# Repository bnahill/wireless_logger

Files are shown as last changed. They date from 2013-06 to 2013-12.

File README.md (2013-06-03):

Wireless Logger
===============

A compact wireless inertial logging and processing hardware platform. This may include multiple designs of different names. Software may also be included soon.

Licensing
=========

Hardware designs in this package are licensed under the TAPR Open Hardware License v1.0.

Software presented here is licensed under the GNU General Public License version 3 (GPLv3).

The terms of both licenses are included in this repository. If you would like to use these works in another projects which would otherwise violate the terms of their respective licenses, please contact me and perhaps we can work something out. While I support both the free hardware/software movements, I understand that such licenses may excessively constrain groups with otherwise noble causes.

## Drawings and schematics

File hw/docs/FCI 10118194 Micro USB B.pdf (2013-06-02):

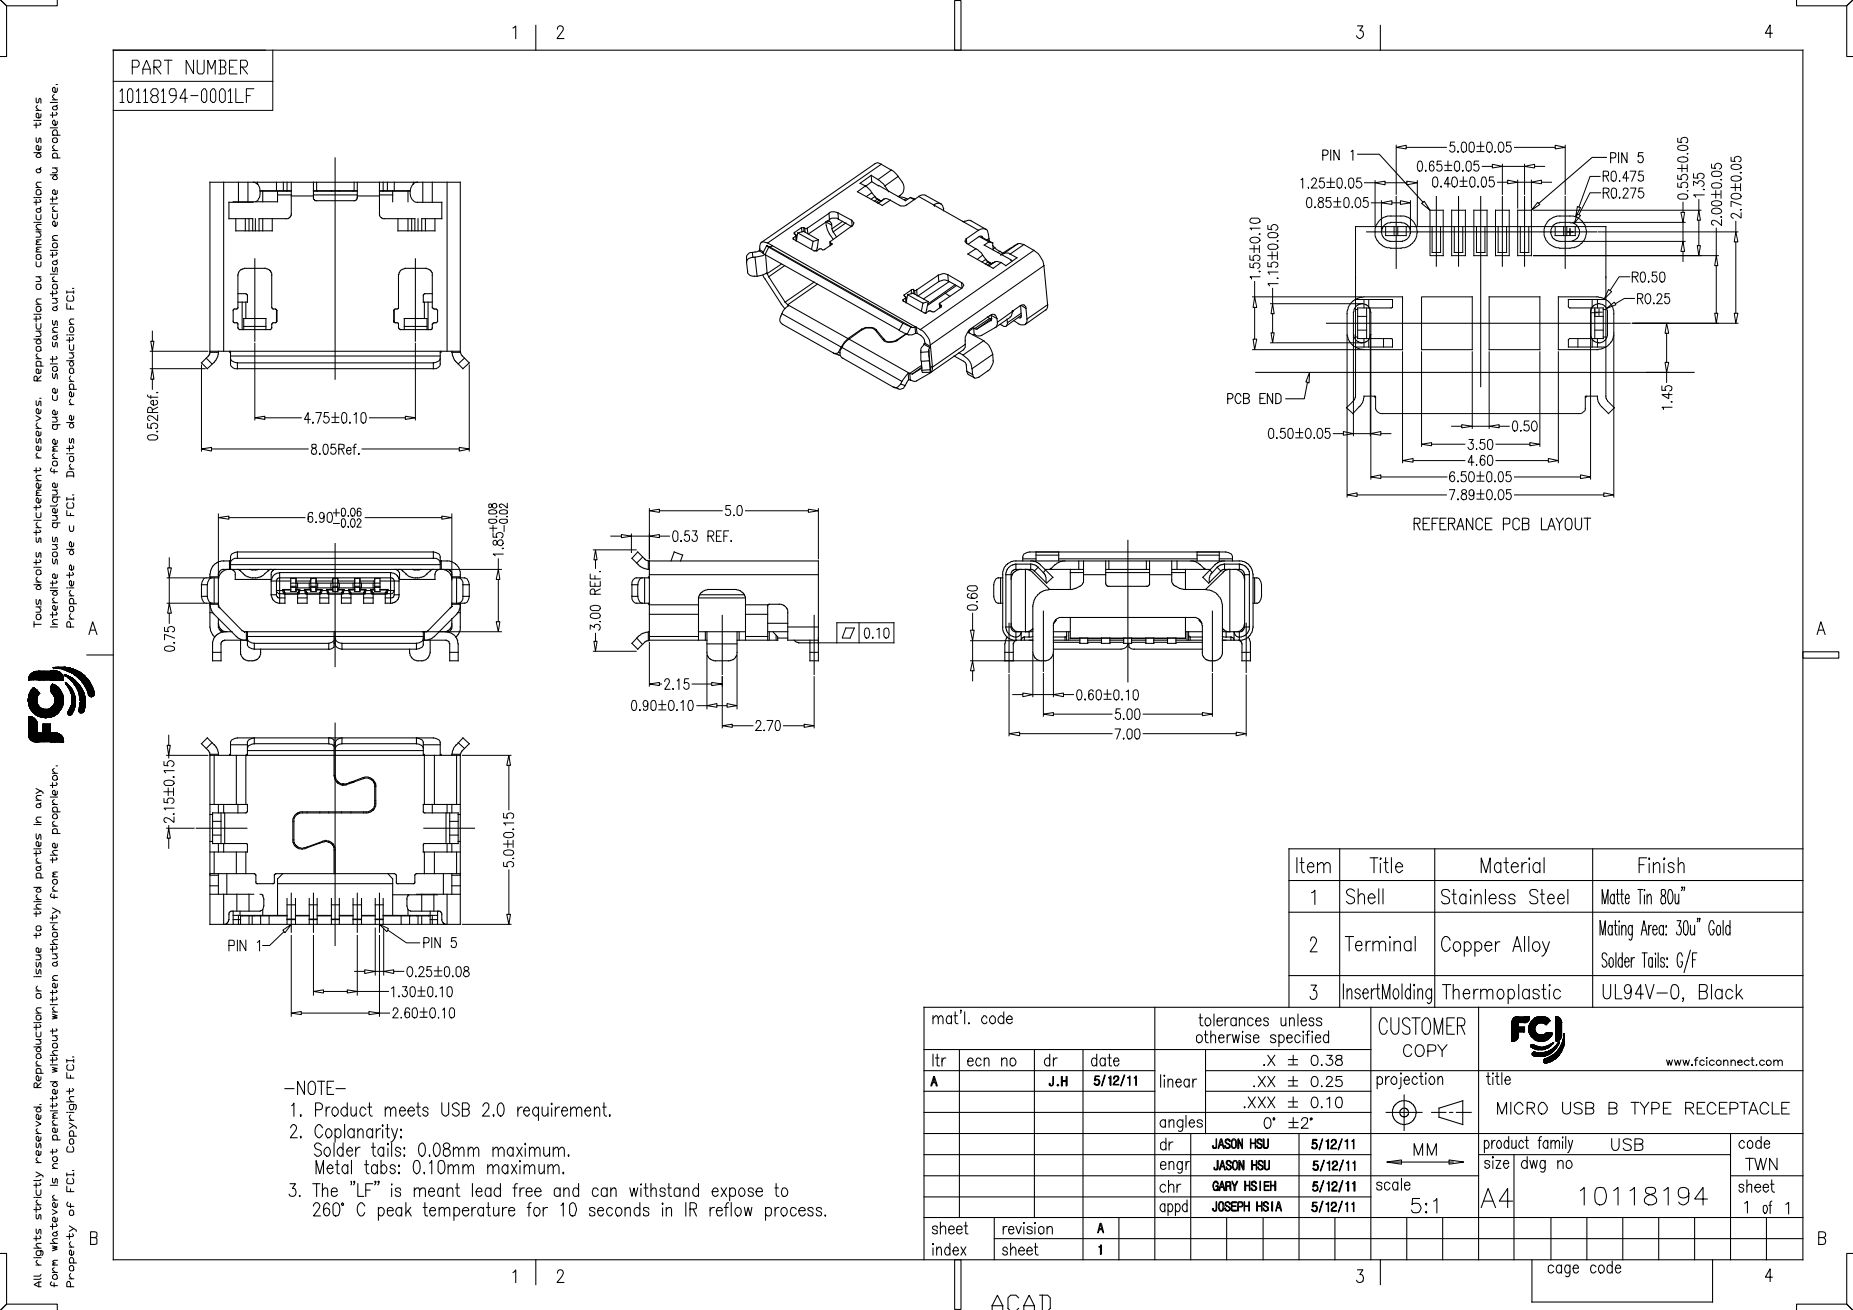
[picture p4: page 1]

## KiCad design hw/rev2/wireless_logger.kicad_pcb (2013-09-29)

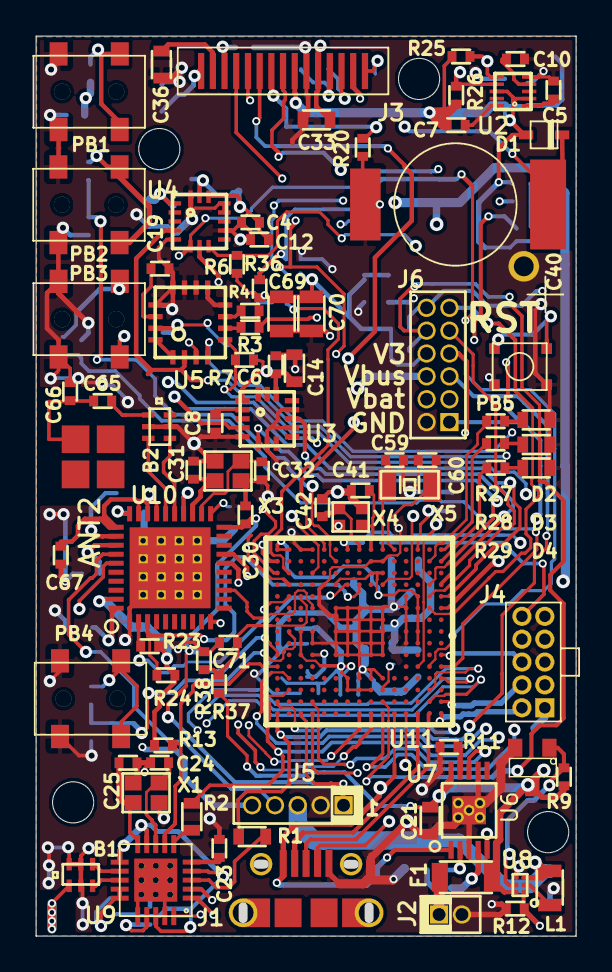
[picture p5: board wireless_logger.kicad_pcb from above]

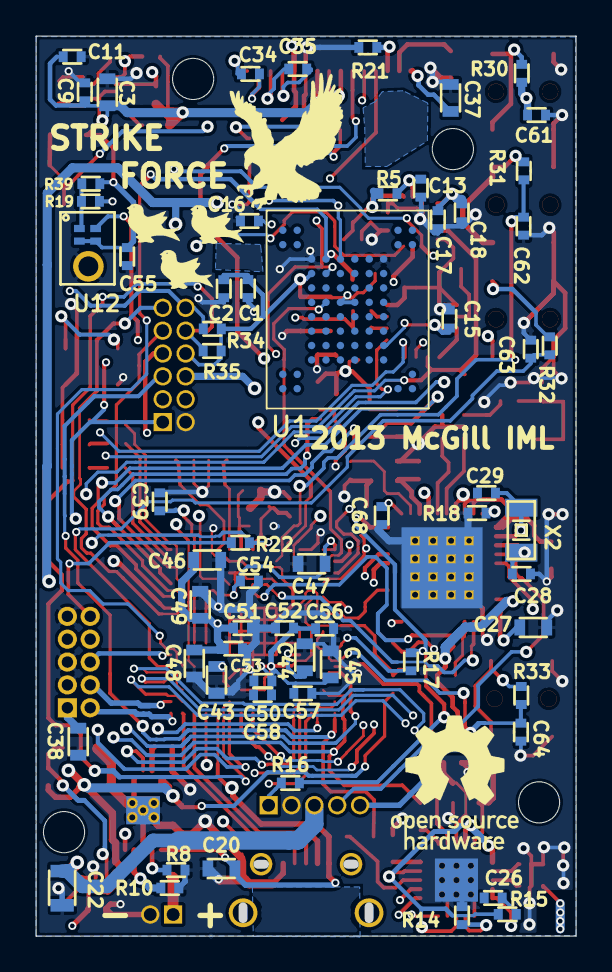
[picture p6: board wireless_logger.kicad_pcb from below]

Board: 4 copper layers, 30.0 x 50.0 mm, 155 parts (66 on the bottom side), 112 nets.

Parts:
ANT2: Molex 47948; MOLEX_47948
B1: 0915BM15A0001; JOHAN_BALUN_FILT
B2: 2450BM15A0002; JOHAN_BALUN_FILT
C1, C55: 0.1u; SMD0402
C2, C7, C18, C34, C35, C67, C68, C71: 1u; SMD0402
C3, C14, C20, C21, C33, C36, C37, C38, C43, C44, C45, C46, C47, C48, C49: 2.2u; SMD0603
C4, C5, C8, C9, C10, C11, C12, C15, C17, C23, C50, C51, C52, C53, C61, C62, C63, C64: 100n; SMD0402
C6, C16: 100p; SMD0402
C13, C19, C26, C39, C54, C56, C57, C58: 10n; SMD0402
C22, C69, C70: 10u; SMD0805
C24, C25, C41, C42: 5p; SMD0402
C27: 1u; SMD0603
C28, C29: 15p; SMD0402
C30: 1n; SMD0402
C31, C32: 12p; SMD0402
C40: DSK-3R3H224U-HL; DSK-XXXXXX-HL
C59, C60: 9p; SMD0402
C65, C66: CAP; SMD0402
D1: BAT43XV2; SOD-523F
D2: LS Q976-NR-1; SMD0603
D3: LW Q38G-Q1S1-3K6L-1; SMD0603
D4: LB Q39E-N1P1-35-1; SMD0603
F1: PTS120616V025; SMD1206
J1: FCI 10118194; FCI_10118194
J2: CONN_2; HDR_2X1_50MIL
J3: SSD1306_SER; LY091WG15
J4: SWD_10PIN; SULLINS_5X2_050_THRU
J5: CONN_5; HDR_5X1_50MIL
J6: CONN_6X2; HDR_6X2_50MIL
L1: MLP2016S1R0M; SMD0805
PAD_0_5x1_5: VAL**; PAD_0_5x1_5
PB1, PB2, PB3, PB4: EVQPSD
PB5: KMT0
R1, R2: 100k; SMD0603
R3, R4: 4.7k; SMD0402
R5: 4.7R; SMD0402
R6, R7, R13: 220k; SMD0402
R8: 1k; SMD0402
R9: 680k; SMD0402
R10: 2k; SMD0402
R11, R12: 470k; SMD0402
R14, R18: 56k (1%); SMD0402
R15: 4R7; SMD0402
R16: 2.7k; SMD0402
R17: 22k; SMD0402
R19: 0R; SMD0402
R20, R36: 100k; SMD0402
R21: 390k; SMD0402
R22, R23, R24, R25, R26, R34, R35: 10k; SMD0402
R27, R28, R29: RES; SMD0402
R30, R31, R32, R33: 3.3k; SMD0402
R37, R38, R39: 1M; SMD0402
SCREW_HOLE_2-56, SCREW_HOLE_2-56#2, SCREW_HOLE_2-56#3, SCREW_HOLE_2-56#4: VAL**; SCREW_HOLE_2-56
U1: MT29FXX01A; MICRON_VFBGA63
U2: MAG3110
U3: MMA8452Q; MMA8451Q
U4: LPS331AP
U5: L3GD20
U6: MCP111T-315; SOT23
U7: BQ24095; BQ24095_MSOP
U8: TPS62698
U9: CC1101
U10: CC2541
U11: STM32F40X_BGA176; STM32F4_BGA176
U12: MEMS_DGTL_MIC; ADMP521
VAL: MCGILL
VAL#2: EAGLE
VAL#3: OSHW
X1: FA-128 26.0000MF10Z-W3; FA-128
X2, X5: 9HT10-32.768KBZF-T; TXC_9HT10
X3: FA-128 32.0000MF20X-K3; FA-128
X4: XRCGB25M000F0L00R0; XRCGB_F_N

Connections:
/Bluetooth/BT_ANT_DN: B2.3, U10.26
/Bluetooth/BT_ANT_DP: B2.4, U10.25
/Bluetooth/BT_ANT_SE: ANT2.1, C65.2, C66.1
/Bluetooth/RF_DC: J5.4, U10.34
/Bluetooth/RF_DD: J5.5, U10.35
/Bluetooth/RF_RESET_N_LOCAL: C30.2, R16.1, R17.1, U10.20
/Bluetooth/RX_MISO: U10.17, U11.H15
/Bluetooth/TX_MOSI: U10.16, U11.G15
/Guardian Interface/GDO0: R2.1, U9.6
/Guardian Interface/GDO2: R1.1, U9.3
/OLED/SCLK: J3.11, U1.K6, U11.P4
/OLED/SDIN: J3.12, U1.J7, U11.R3
/Power/MODE: R12.2, U8.A1, U11.N15
/STM32F4/BT_NRESET: R17.2, U11.R10
/STM32F4/CC1101_nCS: R13.2, U9.7, U11.R11
/STM32F4/EXTI1: R3.1, R4.1, U11.M3
/STM32F4/EXTI2: U10.13, U11.M6
/STM32F4/EXTI5: C61.2, R30.2, U11.P5
/STM32F4/EXTI6: C62.2, R31.2, U11.K2
/STM32F4/EXTI7: C63.2, R32.2, U11.A11
/STM32F4/EXTI8: C64.2, R33.2, U11.P8
/STM32F4/FLASH_nCS: R36.1, U1.K7, U11.B11
/STM32F4/GYRO_nCS: R7.1, U5.5, U11.A6
/STM32F4/I2C2_SCL: R24.2, U10.3, U11.H4
/STM32F4/I2C2_SDA: R23.2, U10.2, U11.J4
/STM32F4/I2C3_SCL: J6.12, R34.2, U11.F15
/STM32F4/I2C3_SDA: J6.10, R35.2, U11.F14
/STM32F4/LED1: R27.2, U11.B2
/STM32F4/LED2: R28.2, U11.A1
/STM32F4/LED3: R29.2, U11.A2
/STM32F4/OLED_nCS: J3.8, U11.L1
/STM32F4/OLED_nD/C: J3.10, U11.R2
/STM32F4/OLED_nRES: J3.9, R20.2, U11.F4
/STM32F4/REG_nCHG: U7.8, U11.M14
/STM32F4/REG_nUSB_CONN: U7.5, U11.M15
/STM32F4/SPI1_MISO: U1.G7, U11.P3
/STM32F4/SPI2_CLK: J6.1, R2.2, R19.1, U11.P13
/STM32F4/SPI2_MISO: J6.3, U11.R14, U12.DAT
/STM32F4/SPI2_MOSI: J6.5, R1.2, U11.R15
/STM32F4/SPI2_NSS: J6.7, U11.P12
/STM32F4/SWCLK: J4.4, U11.A14
/STM32F4/SWDIO: J4.2, U11.A15
/STM32F4/SWO: J4.6, U11.A10
/STM32F4/USART1_RX: J6.9, U11.B5
/STM32F4/USART1_TX: J6.11, U11.B6
/STM32F4/USB_D+: J1.3, U11.B15
/STM32F4/USB_D-: J1.2, U11.C15
/STM32F4/USB_ID: J1.4, U11.D15
/Sensors/ACC_I2C_SCL: R26.2, U2.7, U3.4, U11.A5
/Sensors/ACC_I2C_SDA: R25.2, U2.6, U3.6, U11.B4
/Sensors/ACC_INT1: U3.11, U11.A4
/Sensors/GYR_DRDY_INT2: R3.2, U5.6
/Sensors/GYR_INT1: R4.2, U5.7
/Sensors/GYR_SPI_CLK: U4.4, U5.2, U9.1, U11.B14
/Sensors/GYR_SPI_MISO: U4.7, U5.4, U9.2, U11.B13
/Sensors/GYR_SPI_MOSI: U4.6, U5.3, U9.20, U11.A12
/Sensors/PRS_SPI_nCS: R6.1, U4.8, U11.C11
GND: B1.2, B1.5, B1.6, B2.2, B2.5, B2.6, C1.1, C2.1, C3.1, C4.1, C5.1, C6.1, C7.1, C8.1, C9.1, C10.1, C11.1, C12.1, C13.1, C14.1, C15.1, C16.1, C17.1, C18.1, C19.2, C20.1, C21.1, C22.1, C23.1, C24.1, C25.1, C26.1, C27.1, C28.2, C29.2, C30.1, C31.2, C32.2, C33.1, C36.1, C37.1, C38.1, C39.1, C40.2, C41.2, C42.2, C43.1, C44.1, C45.1, C46.1, C47.1, C48.1, C49.1, C50.1, C51.1, C52.1, C53.1, C54.1, C55.1, C56.1, C57.1, C58.1, C59.2, C60.2, C61.1, C62.1, C63.1, C64.1, C66.2, C67.1, C68.1, C69.1, C70.1, C71.1, D2.2, D3.2, D4.2, J1.5, J2.2, J3.6, J4.3, J4.5, J4.9, J5.2, J6.2, PB1.2, PB2.2, PB3.2, PB4.2, PB5.2, R8.1, R10.1, R11.1, R12.1, R14.1, R18.2, R20.1, R21.1, R38.1, U1.K3, U1.K8, U2.5, U2.10, U3.5, U3.7, U3.10, U3.12, U4.5, U4.10, U4.12, U4.13, U4.16, U5.8, U5.9, U5.10, U5.11, U5.12, U5.13, U6.2, U7.3, U7.7, U7.GND, U8.C2, U9.16, U9.19, U9.GND, U10.1, U10.GND, U11.D5, U11.D6, U11.D7, U11.D8, U11.D9, U11.F2, U11.F6, U11.F7, U11.F8, U11.F9, U11.F10, U11.F12, U11.G2, U11.G6, U11.G7, U11.G8, U11.G9, U11.G10, U11.G12, U11.H6, U11.H7, U11.H8, U11.H9, U11.H10, U11.H12, U11.J6, U11.J7, U11.J8, U11.J9, U11.J10, U11.K6, U11.K7, U11.K8, U11.K9, U11.K10, U11.L4, U11.M1, U11.M8, U11.M9, U11.N1, U12.GND, X1.GND, X3.GND, X4.GND
unnamed: PB2.1, R31.1
unnamed: PB4.1, R33.1
unnamed: PB3.1, R32.1
unnamed: PB1.1, R30.1
unnamed: R19.2, R39.2, U12.CLK
unnamed: C60.1, U11.E1, X5.1
unnamed: C39.2, C40.1, D1.2, U11.C1
unnamed: C43.2, U11.F13
unnamed: C44.2, U11.M10
unnamed: J4.10, R22.2
unnamed: C42.1, U11.H1, X4.2
unnamed: C41.1, U11.G1, X4.1
unnamed: C71.2, R37.1, R38.2, U11.N5
unnamed: C59.1, U11.F1, X5.2
unnamed: D2.1, R27.1
unnamed: D4.1, R29.1
unnamed: D3.1, R28.1
unnamed: PB5.1, R22.1, U11.J1
unnamed: C13.2, R5.2, U4.15
unnamed: C5.2, U2.1
unnamed: C10.2, U2.4
unnamed: C8.2, U3.2
unnamed: C19.1, U5.14
unnamed: R8.2, U7.2
unnamed: R11.2, U7.9
unnamed: R10.2, U7.4
unnamed: L1.1, U8.B1
unnamed: F1.1, J2.1
unnamed: R9.1, U6.1, U8.B2
unnamed: R14.2, U9.17
unnamed: C24.2, U9.8, X1.1
unnamed: C25.2, U9.10, X1.2
unnamed: C26.2, R15.1, U9.14, U9.15
unnamed: B1.3, U9.13
unnamed: B1.4, U9.12
unnamed: C23.2, U9.5
unnamed: R18.1, U10.30
unnamed: C27.2, U10.40
unnamed: C29.1, U10.32, X2.2
unnamed: B2.1, C65.1
unnamed: C28.1, U10.33, X2.1
unnamed: J5.1, R16.2
unnamed: C32.1, U10.22, X3.1
unnamed: C31.1, U10.23, X3.2
unnamed: C37.2, J3.15
unnamed: C36.2, J3.14
unnamed: J3.13, R21.2
unnamed: C34.2, J3.2
unnamed: C34.1, J3.1
unnamed: C35.1, J3.3
unnamed: C35.2, J3.4
V3: C1.2, C2.2, C3.2, C4.2, C6.2, C7.2, C9.2, C11.2, C12.2, C14.2, C15.2, C16.2, C17.2, C18.2, C22.2, C38.2, C45.2, C46.2, C47.2, C48.2, C49.2, C50.2, C51.2, C52.2, C53.2, C54.2, C55.2, C56.2, C57.2, C58.2, C67.2, C68.2, C69.2, C70.2, D1.1, J3.7, J4.1, J5.3, J6.8, L1.2, R5.1, R6.2, R7.2, R13.1, R15.2, R23.1, R24.1, R25.1, R26.1, R34.1, R35.1, R36.2, R39.1, U1.D3, U1.G5, U1.G6, U1.J8, U2.2, U2.8, U3.1, U3.14, U4.1, U4.14, U5.1, U5.15, U5.16, U8.C1, U9.4, U9.9, U9.11, U9.18, U10.10, U10.21, U10.24, U10.27, U10.28, U10.29, U10.31, U10.39, U11.C5, U11.C6, U11.C7, U11.C8, U11.C9, U11.F3, U11.G3, U11.G13, U11.H13, U11.J12, U11.J13, U11.K4, U11.N8, U11.N9, U11.N10, U11.P1, U11.R1, U12.LR, U12.VDD
Vbat: C21.2, C33.2, F1.2, J3.5, J6.4, R9.2, R37.2, U6.3, U7.10, U8.A2
Vbus: C20.2, J1.1, J6.6, U7.1, U11.E15

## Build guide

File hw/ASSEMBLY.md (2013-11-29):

Hardware Assembly
=================
This document refers to **rev2c**. Rev2a and b are no longer supported and no hardware of those revisions should be assembled.

**Note for rev2a-c: XRCGB crystal footprints are flipped! This applies to the 25MHz, 26MHz, and 32MHz crystals in the design. It's easy enough to mount them rotated 90 degrees but also please take a moment to consider the value of design reviews. Unfortunately, they only help if the documentation is actually clear about whether a given drawing is from top or bottom...**

This document does not teach any skills involved. If you don't have experience with hot air reworking and soldering, you will have a very uncomfortable time and are extremely likely to break things. A lifted pad under any component can mean the entire board and many of the components on it are wasted, so please practice on something else first. THIS IS NOT AN EASY BOARD TO ASSEMBLE.

Assembly of the Strike Force rev2c board requires a number of tools:
* Soldering iron
* Hot-air rework station (prefered) or oven
* Vise
* Fine tweezers
* A solder paste in a syringe
* Solder wire of your choice, preferably thin (0.08cm will do, smaller preferable)
* Some flux, preferably in pen form
* Kapton (or other high-temperature) tape (maybe not required)
* Microscope (optional)

For assembly by hand, I recommend assembling the board in stages, defined by both regions and functionality, to reduce the search space if errors occur.

First, I recommend to assemble the power supply. Add all components in the region, including the USB port. This is to ensure that the rest of the components will receive a safe voltage when they are populated. Mounting the TPS62698 is not as bad as it looks as long as you get the orientation right. Pin A1 is the one with a dot over it... Use a microscope if you are unsure of the placement. Verify the 4.2V and ~3V supplies with the USB cable plugged in.

Second, mount the processor. This one is finicky and so I recommend adding all of the nearby passive components on the back before soldering on the processor. This way, you won't end up reflowing any of the processor while adding them. Mount both the 32kHz and 25MHz crystals along with the processor for the exact same reason. Once that's done, add the SWD connector (using the iron) and verify that the board and crystals work.

Next, you are free to add whichever sensors and radio units you please. I advise that the last components be, in sequence, the flash memory, the supercapacitor, and the OLED display. These are each sensitive to falling off the board when reflowed and are at risk of such an accident.

All components are sensitive to heat and care should be taken to minimize the time and temperature while soldering. However, there are a few components that are particularly sensitive to this:
* The microphone must not have hot air blown into its port hole. Just don't do it. Tape over it if you are soldering near it from that side.
* The pressure sensor is sensitive to hot air on the top hole. I recommend covering the device in Kapton tape and trimming the edges before soldering.
Everything else has survived a fair bit of abuse in my experience, but you should still be careful...

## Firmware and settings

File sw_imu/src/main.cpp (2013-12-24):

#include "ch.h"
#include "hal.h"

#include "platform.h"
#include "acquisition.h"

#include "ui/ui.h"
#include "power_management.h"


extern "C"{
	int main(void);
}

using namespace Platform;


int main(void) {
	halInit();
	chSysInit();

	Platform::early_init();
	
	clk_mgr_req_hsi();




#if SCHED_TICK_RTC
	PowerManagement::disable_systick();
	PowerManagement::enable_rtc_tick();
#endif
	oled.init();

//  if(!guardian1.init()) {
// 		evt_log.add("Guardian init\nfailed!", EventItem::SEVERITY_ERROR);
// 	}

	Acquisition::init();

	UI::start();

	//Acquisition::require_sources(Acquisition::SRC_ACC1 |
	//							 Acquisition::SRC_MAG1 |
	//							 Acquisition::SRC_GYRO1);
	clk_mgr_noreq_hsi();

// 	while(1){
// 		led1.toggle();
// 		chThdSleep(MS2ST(1000));
// 	}

#ifdef BOARD_SF
	while(true){
		chThdSleep(TIME_INFINITE);
//		chThdSleep(MS2ST(200));
//		led1.toggle();
// 		chThdSleep(MS2ST(200));
// 		led2.toggle();
// 		chThdSleep(MS2ST(200));
// 		led3.toggle();
	}
#endif

	return 1;
}

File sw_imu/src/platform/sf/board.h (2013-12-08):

/*
    ChibiOS/RT - Copyright (C) 2006,2007,2008,2009,2010,
                 2011,2012 Giovanni Di Sirio.

    This file is part of ChibiOS/RT.

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
                                      ---

    A special exception to the GPL can be applied should you wish to distribute
    a combined work that includes ChibiOS/RT, without being obliged to provide
    the source code for any proprietary components. See the file exception.txt
    for full details of how and when the exception can be applied.
*/

#ifndef _BOARD_H_
#define _BOARD_H_

//! @addtogroup Platform
//! @{
//! @addtogroup ChibiOS
//! @{

/*
 * Setup for STMicroelectronics STM32F4-Discovery board.
 */

/*
 * Board identifier.
 */
#define BOARD_ST_STM32F4_DISCOVERY
#define BOARD_NAME              "ST STM32F4-Discovery"

/*
 * Board frequencies.
 * NOTE: The LSE crystal is not fitted by default on the board.
 */
#define STM32_LSECLK            32768
//#define STM32_HSECLK            8000000

/*
 * Board voltages.
 * Required for performance limits calculation.
 */
#define STM32_VDD               300

/*
 * MCU type as defined in the ST header file stm32f4xx.h.
 */
#define STM32F4XX

/*
 * IO pins assignments.
 */

#define GPIOA_UART4_TX          0
#define GPIOA_UART4_RX          1
#define GPIOA_OLED_NDC          3
#define GPIOA_SPI1_SCK          5
#define GPIOA_SPI1_MISO         6
#define GPIOA_SPI1_MOSI         7
#define GPIOA_I2C3_SCL          8
#define GPIOA_VBUS_FS           9
#define GPIOA_OTG_FS_ID         10
#define GPIOA_OTG_FS_DM         11
#define GPIOA_OTG_FS_DP         12
#define GPIOA_SWDIO             13
#define GPIOA_SWCLK             14

#define GPIOB_SWO               3
#define GPIOB_GYRO_NCS          5
#define GPIOB_USART1_TX         6
#define GPIOB_USART1_RX         7
#define GPIOB_I2C1_SCL          8
#define GPIOB_I2C1_SDA          9
#define GPIOB_SPI2_NSS          12
#define GPIOB_SPI2_SCK          13
#define GPIOB_SPI2_MISO         14
#define GPIOB_SPI2_MOSI         15

#define GPIOC_GYR_INT           1
#define GPIOC_BATT_MON          4
#define GPIOC_BUTTON1           5
#define GPIOC_USART6_TX         6
#define GPIOC_USART6_RX         7
#define GPIOC_I2C3_SDA          9
#define GPIOC_SPI3_SCK          10
#define GPIOC_SPI3_MISO         11
#define GPIOC_SPI3_MOSI         12

#define GPIOD_PRS_NCS           5
#define GPIOD_FLASH_NCS         6
#define GPIOD_BUTTON3           7
#define GPIOD_REG_MODE          10
#define GPIOD_REG_NUSB_CONN     13
#define GPIOD_REG_NCHG          14

#define GPIOE_ACC_INT1          0
#define GPIOE_LED3              2
#define GPIOE_LED2              3
#define GPIOE_OLED_EN           4
#define GPIOE_LED1              5
#define GPIOE_BUTTON4           8
#define GPIOE_BT_NRESET         12
#define GPIOE_CC1101_NCS        15

#define GPIOF_BUTTON2           6
#define GPIOF_OLED_NCS          10

#define GPIOH_OSC_IN            0
#define GPIOH_OSC_OUT           1
#define GPIOH_OLED_NRES         2
#define GPIOH_I2C2_SCL          4
#define GPIOH_I2C2_SDA          5
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

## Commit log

2013-05-10 Started rev2 of logger with bigger MCU and better power management
    [power.sch, sensors.sch, stm32f4.sch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]
2013-05-16 Schematic nearly final, placement beginning
    [bluetooth.sch, bluetooth_nordic.sch, oled.sch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]
2013-05-29 Uhhhh, secondary interconnect assignment and a LOT of routing
    [bluetooth.sch, oled.sch, power.sch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]
2013-05-29 Optimized some routes and passes DRC. Still need to do RF traces
    [wireless_logger.kicad_pcb]
2013-05-31 Ready for first schematic review
    [bluetooth.sch, oled.sch, power.sch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]
2013-06-01 Route and placement optimization. Added holes. Reduced number of ports used
    [bluetooth.sch, oled.sch, power.sch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]
2013-06-01 Updated BQ24095 to MSOP package (free samples) and verified connections
    [wireless_logger.kicad_pcb]
2013-06-01 Fixed huge problem with regulator footprint pin layout
    [bluetooth.sch, oled.sch, power.sch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]
2013-06-01 Added pullup to flash nCS
    [bluetooth.sch, oled.sch, power.sch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]
2013-06-01 Added some extra decoupling caps for bluetooth
    [bluetooth.sch, oled.sch, power.sch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]
2013-06-01 Minor rerouting stuffs
    [wireless_logger.kicad_pcb]
2013-06-02 STM32 checked -- Some optimization done on routes and important filtering bits
    [wireless_logger.kicad_pcb]
2013-06-02 Fixed misconnected CC1101 debug output to SPI2
    [bluetooth.sch, oled.sch, power.sch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]
2013-06-02 Added regulator datasheet
2013-06-03 Moved silks around!
    [bluetooth.sch, oled.sch, power.sch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]
2013-06-03 Rev 2a submitted to OSH Park for manufacture
    [wireless_logger-B_Cu.gbl, wireless_logger-B_Mask.gbs, wireless_logger-B_SilkS.gbo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]
2013-06-04 Set soldermask clearance to zero
    [wireless_logger.kicad_pcb]
2013-06-24 Changed P1 to J6. This was changed for the silks on rev2a but not back-annotated
    [bluetooth.sch, oled.sch, power.sch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]
2013-07-10 Updated PCB to 5 mil trace/space for more-reasonably-sized BGA pads
    [wireless_logger.kicad_pcb]
2013-07-11 Added isolation for flash power and battery voltage monitoring
    [wireless_logger.kicad_pcb, wireless_logger.sch]
2013-07-12 Finished more small connections
    [bluetooth.sch, oled.sch, power.sch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]
2013-07-12 Added super-slick graphics and standardized silk print sizes
    [wireless_logger.kicad_pcb]
2013-07-14 Moved to NSMD BGA mounting and moved silks around.
    [wireless_logger.kicad_pcb]
2013-07-16 Hardware rev2b submitted for manufacturing. Minor touchups.
    [bluetooth.sch, oled.sch, power.sch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]
2013-08-20 More advanced EXTI control, added support for LSM303 interrupts (not working)
2013-08-20 Added MAG3110 driver
2013-08-20 A few things: Added L3GD20 gyroscope and corresponding SPI drivers. Added Platform namespace for all platform-specific configuration stuff Added a bunch more documentation for various things Added im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
2013-08-20 A lot of things... FANCY new SPI drivers OLED driver Framebuffer Font library
2013-08-20 Added more fonts and made a common interface to all sensor readings
2013-08-20 Enabled (and fixed) more compiler warnings
    [l3gd20.cpp, main.cpp, mma8452q.cpp]
2013-08-20 Made it possible to adjust output rate of accelerometer
2013-08-20 Added an acquisition event source for sensor results
2013-08-20 More early developments in wireless
2013-08-20 Reorganized exernal interrupts in a non-interruptcentric way Also make CC1101 initialize correctly
    [board.h, main.cpp]
2013-08-20 Added basic Guardian driver to control CC1101
2013-08-20 Added basic clock speed switching
2013-08-20 Added Coffee FS and some minimal Contiki components Added a few new UI items including a basic test suite Got flash driver working too
2013-08-20 Started fixing problems with the filesystem not really being flash-friendly
    [main.cpp]
2013-08-20 Fixed up both CC1101 and Guardian drivers to initialize properly
    [cc1101.cpp]
2013-08-20 Replaces vector inversion with optimized assembly
2013-08-20 Made buttons use some fancy debouncing
2013-08-20 Added a fancy and efficient print function
2013-08-20 Added untested support for queueing of sensor data
2013-08-20 Fixed the sensor queuing!
    [main.cpp]
2013-08-20 Fix to flash continued read and lots of USB interface improvements
    [main.cpp, mt29fxg01.cpp]
2013-08-20 Fixed multi-sector writes. Screw you Micron. Your documentation is crap.
    [mt29fxg01.cpp]
2013-08-20 Got rid of excessive printing when recieving large buffers
2013-08-20 Added some super-slick clock and sensor management stuff: Scheduler runs fine of RTC Switches to HSI/HSE as needed by applications Automatically enable and disable each sensor as required
2013-08-20 Added options for ChibiOS debugging, also fixed accelerometer acquisition
2013-08-20 Moved board-dependent platform stuff around
2013-08-20 Made UI completely static, added sensor logging test, allowed timeout in UI wait_for_button
2013-08-20 Platform init mounts flash
2013-08-20 Fixed up accelerometer driver to be templated for different variants
    [main.cpp, mma845x.cpp]
2013-08-20 Stop flashing the LED on clock changes...
2013-08-21 Fixed SF board configuration for GPIOB/I2C1
    [board.h]
2013-09-12 MADE SPI RUN IN APPLICATION THREADS FOR BETTER RESPONSIVENESS Patched up UI for SF
2013-09-21 Initialize button states correctly...
2013-09-21 Fixed MMA845x scaling for 12/14-bit devices
    [mma845x.cpp]
2013-09-21 Fixed I2C peripherals on SF
    [board.h]
2013-09-21 More explicit SPI initialization in flash module
2013-09-24 Prepared upgrade to hw rev2c: Changes: Larger pads on flash BGA for easier mounting Move a few signals that were close to sensitive clock connections Remap more things to SPI1, USART1, and USART6 to 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
    [bluetooth.sch, oled.sch, power.sch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]
2013-09-27 Submitted rev2c for manufacturing
    [wireless_logger-B_Cu.gbl, wireless_logger-B_Mask.gbs, wireless_logger-B_SilkS.gbo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]
2013-09-29 Tiny update to bottom silk screen. This acutally made it into the manufacturing of rev2c by email
    [wireless_logger.kicad_pcb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]
2013-11-27 Updated to hw rev2c pin and peripheral mapping Also got rid of semaphore synchronization for MMA845x, should do others Also added more documentation to acquisition framework
2013-11-27 Add some hardware assembly instructions
2013-11-27 Fixed incorrect SPI assignment for gyro also insufficent stack size for acquisition threads
2013-11-27 Added more assembly notes regarding crystal orientation debacle
2013-11-27 Added assembly note about TPS62698
2013-11-27 Corrected formatting on assembly instructions
2013-12-02 Upgraded ChibiOS to 2.6.1 to fix some HAL bugs kicking around So far, the only problem is a hardfault in FlogFS mounting now That will be dealt with later, in a session dedicated to fixing FlogFS
    [main.cpp]
2013-12-05 Added 'back' button support in UI
2013-12-08 Holy crap -- a lot, but it's all intertwined and so is lumped together -Datasources now name the types required for more-easily defined listeners -Fractional types introduced; hopefully let sensors u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
    [board.h, lps331.cpp]
2013-12-24 Fixed FLogFS and flash initialization failure Both areas followed a messed up sequence upon failure due to incorrect error checking.
    [mt29fxg01.cpp]
2013-12-24 Fixed suspend not being reenabled after sensorview
